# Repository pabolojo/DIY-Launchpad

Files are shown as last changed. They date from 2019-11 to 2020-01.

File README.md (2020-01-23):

# DIY-Launchpad

## This project is a DIY Launchpad powered by an Arduino, it is compatible with every Music Production program or app which can recognize USB MIDI devices, like Ableton Live.

## Instructions:

1. First you will need to gather all the parts and tools shown below, which are required for this project:

### Parts
|Units| Name|Cost (€)| Image|
|:--:|:---:|:---:|:---:|
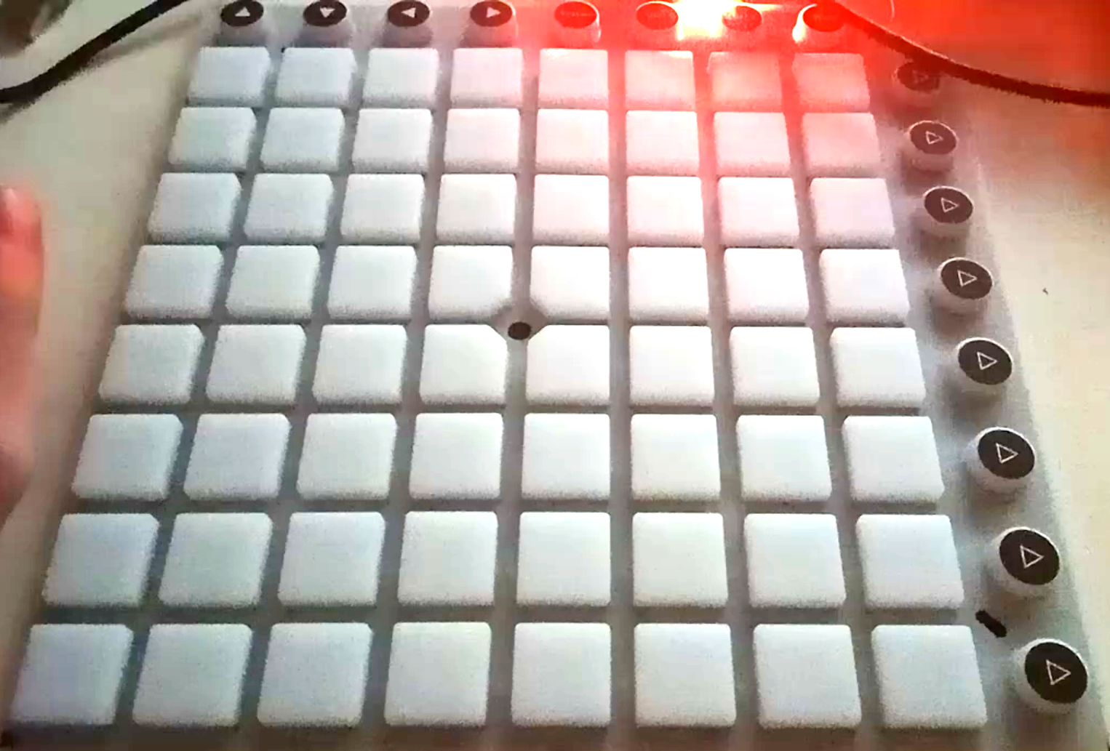
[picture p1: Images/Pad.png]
|1|Rubber Pad|20||
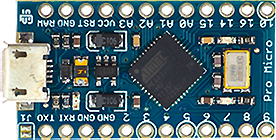
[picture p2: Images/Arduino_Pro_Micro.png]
|1|Arduino Pro Micro|2.5||
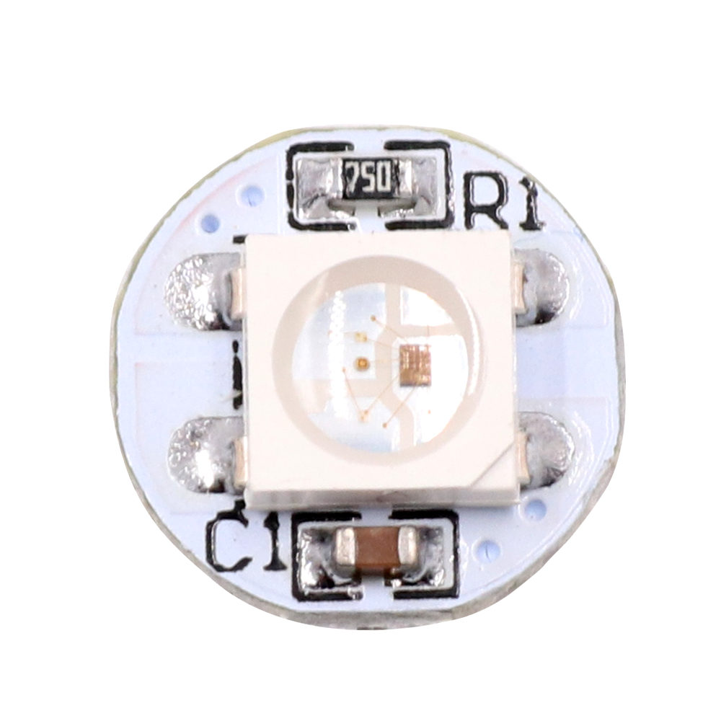
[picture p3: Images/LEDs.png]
|80|WS2812B RGB LEDs|8||
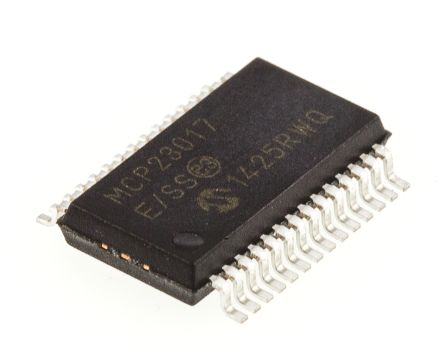
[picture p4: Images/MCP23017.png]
|5|MCP23017 - E/SS|4||
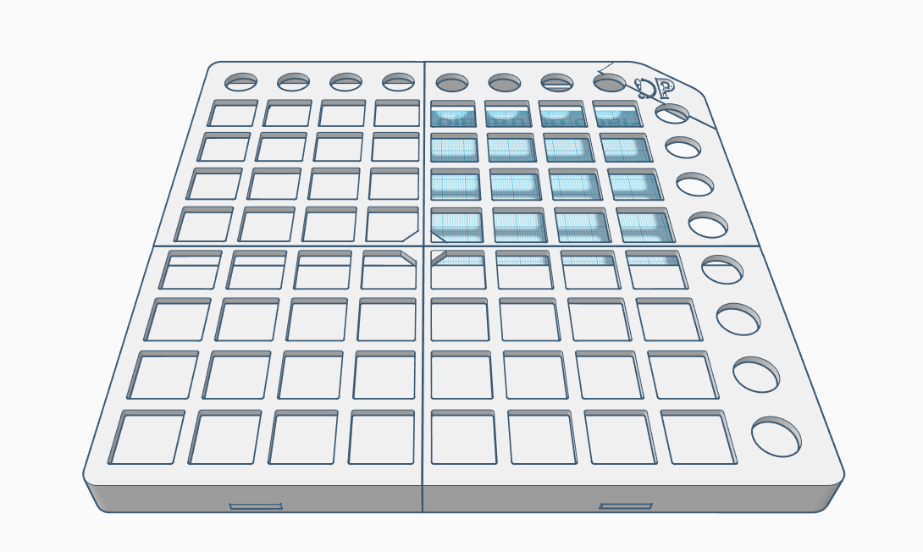
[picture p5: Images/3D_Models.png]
|1|3D Printed pieces Set|15||
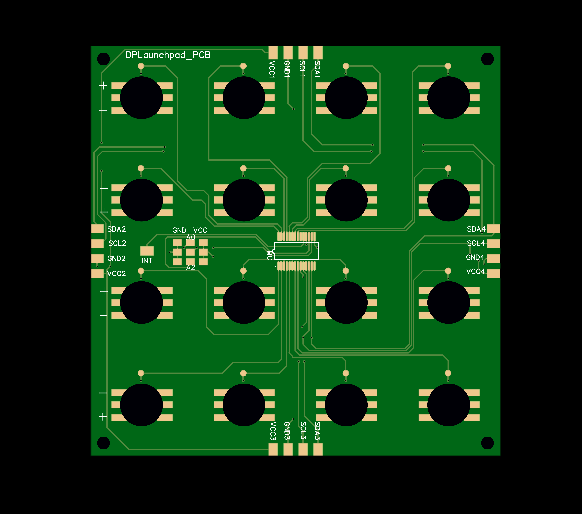
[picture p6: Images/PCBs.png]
|1|PCB Launchpad Set|10||

### Tools / Materials
|Name|Image|
|:---:|:---:|
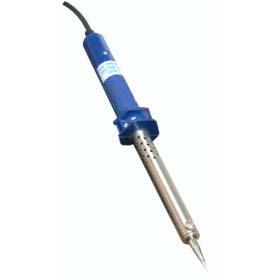
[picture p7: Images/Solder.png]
|Tin Solder||
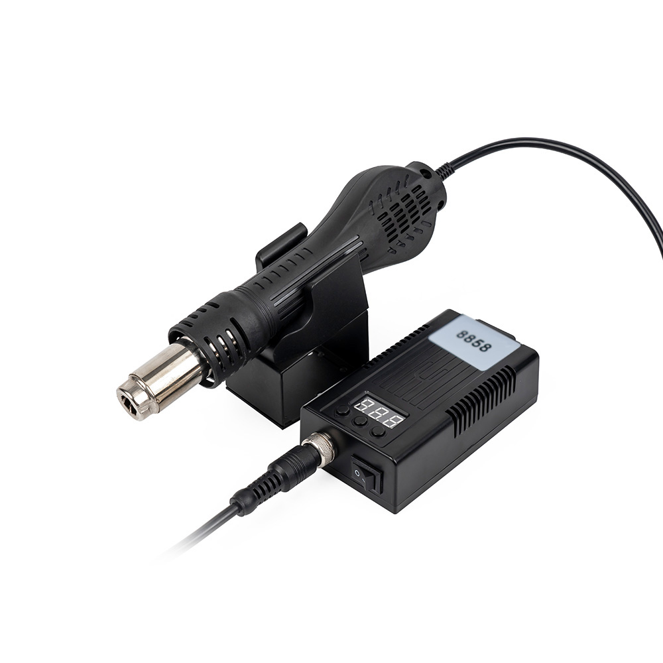
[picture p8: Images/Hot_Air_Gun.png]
|Hot Air Gun (Recommended)||
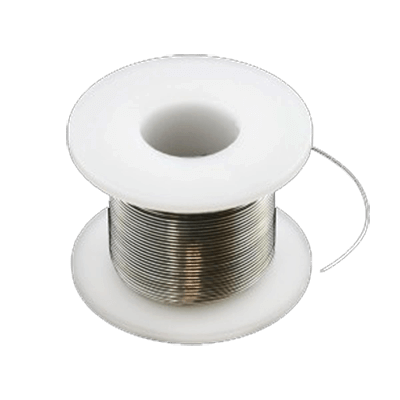
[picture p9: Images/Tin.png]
|Tin||
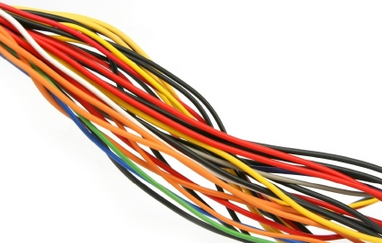
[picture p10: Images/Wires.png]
|Wires||

2. Then you will need to solder the MCP23017-E/SO integrated circuits to the PCBs using the Hot Air gun, as well as the PCBs one another connecting their pads, and the WS2812B RGB LEDs with the aid of the Tin Solder and metal wire. Assign an different address to each one of the PCBs by shortcuting A0, A1 and A2 either with GND or VCC. Then make the following connections between the Arduino Pro Micro and the PCBs:

|Arduino Pin|PCB Pad|
|:---:|:---:|
|2|SDA|
|3|SCL|
|VCC|VCC|
|GND|GND|

You may also make sure to connect the first WS2812B RGB LED of your array to the Arduino, connecting:

|Arduino Pin|LEDs Pad|
|:---:|:---:|
|VCC|VCC|
|GND|GND|
|10|DATA|

As well as the interrupt pads of the PCBs (grouping them by pairs) as shown:

|Arduino Pin|Interrupt (INT)|
|:---:|:---:|
|0|1 and 2|
|1|3 and 4|
|7|5|

The final result should be something like this:

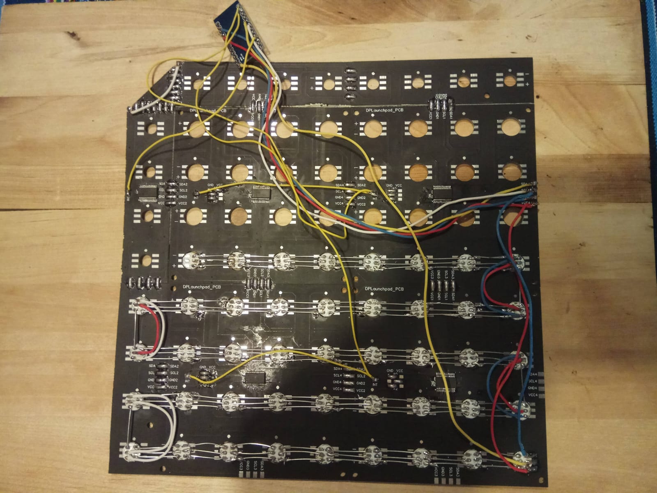
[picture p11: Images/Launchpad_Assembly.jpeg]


3. Flash the firmware to the Arduino Pro Micro, 3D print the housing, assembly everything and enjoy. :)



## This is still an ongoing project, and many things have to be fixed/improved yet, feel free to comment the project or make any suggestion you think it would make it better!

If you want to know what I am currently working on, visit http://psoetardgarcia.ga/

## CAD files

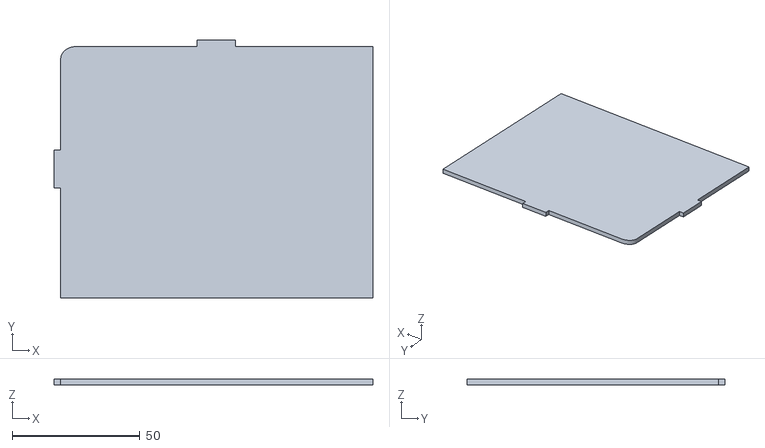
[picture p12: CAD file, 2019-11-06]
3D_Models/Launchpad_BR_C.stl
125.0 x 101.0 x 2.40

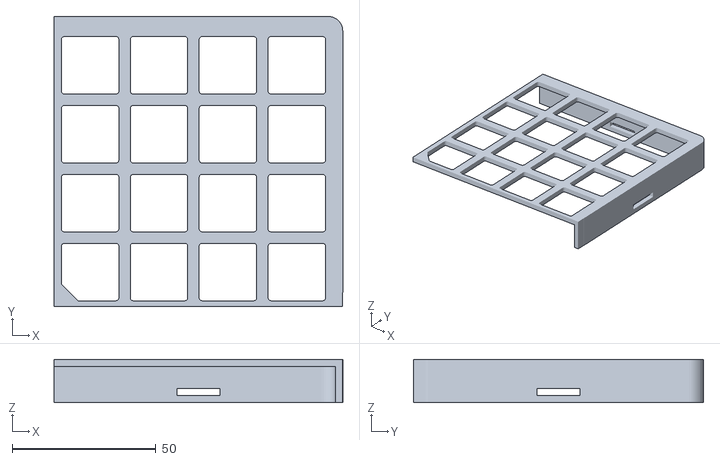
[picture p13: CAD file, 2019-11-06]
3D_Models/Launchpad_BL.stl
100.5 x 101.0 x 15.0

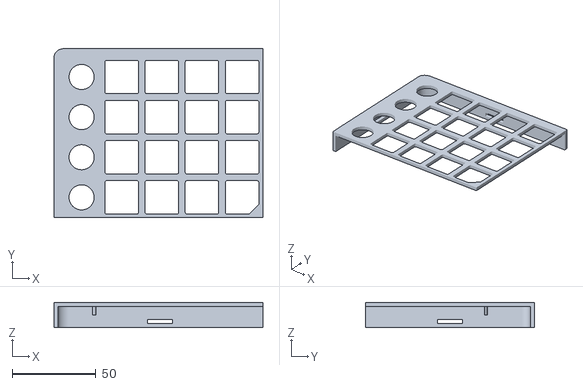
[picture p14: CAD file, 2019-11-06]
3D_Models/Launchpad_BR.stl
125.0 x 101.0 x 15.0

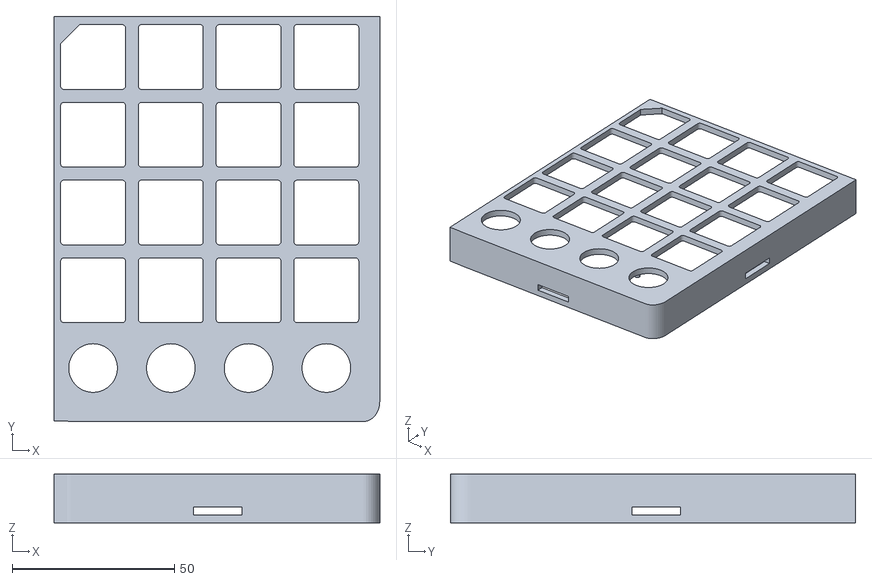
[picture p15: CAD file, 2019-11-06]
3D_Models/Launchpad_TL.stl
100.5 x 125.0 x 15.0

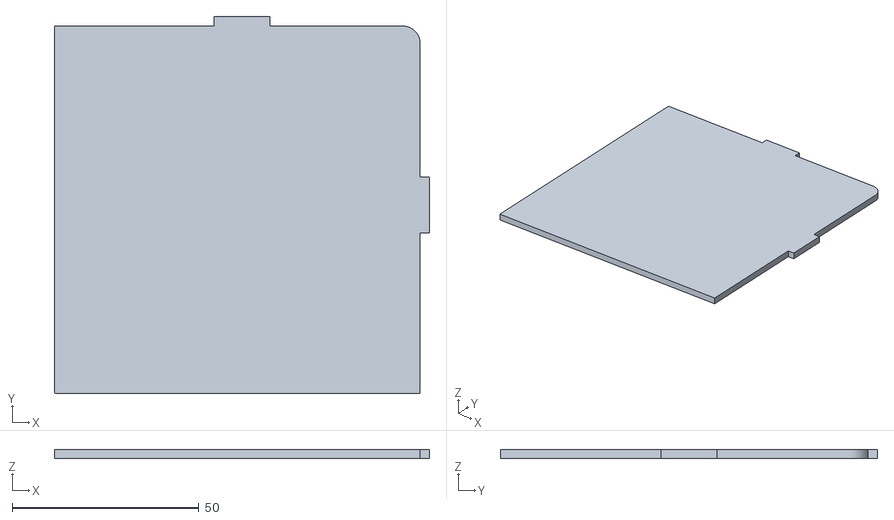
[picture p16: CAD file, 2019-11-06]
3D_Models/Launchpad_BL_C.stl
100.5 x 101.0 x 2.40

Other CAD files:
3D_Models/Launchpad_TL_C.stl

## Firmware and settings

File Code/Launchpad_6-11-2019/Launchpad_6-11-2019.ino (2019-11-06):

#include <Wire.h>
#include "MIDIUSB.h"
#include "FastLED.h"

#define NUM_LEDS 44
#define DATA_PIN 10
CRGB leds[NUM_LEDS];

// MCP23017 registers (everything except direction defaults to 0)

#define IODIRA   0x00   // IO direction  (0 = output, 1 = input (Default))
#define IODIRB   0x01
#define IOPOLA   0x02   // IO polarity   (0 = normal, 1 = inverse)
#define IOPOLB   0x03
#define GPINTENA 0x04   // Interrupt on change (0 = disable, 1 = enable)
#define GPINTENB 0x05
#define DEFVALA  0x06   // Default comparison for interrupt on change (interrupts on opposite)
#define DEFVALB  0x07
#define INTCONA  0x08   // Interrupt control (0 = interrupt on change from previous, 1 = interrupt on change from DEFVAL)
#define INTCONB  0x09
#define IOCON    0x0A   // IO Configuration: bank/mirror/seqop/disslw/haen/odr/intpol/notimp
//#define IOCON 0x0B  // same as 0x0A
#define GPPUA    0x0C   // Pull-up resistor (0 = disabled, 1 = enabled)
#define GPPUB    0x0D
#define INFTFA   0x0E   // Interrupt flag (read only) : (0 = no interrupt, 1 = pin caused interrupt)
#define INFTFB   0x0F
#define INTCAPA  0x10   // Interrupt capture (read only) : value of GPIO at time of last interrupt
#define INTCAPB  0x11
#define GPIOA    0x12   // add1 value. Write to change, read to obtain value
#define GPIOB    0x13
#define OLLATA   0x14   // Output latch. Write to latch output.
#define OLLATB   0x15


#define add1 0x20  // MCP23017 is on I2C add1 0x20
#define add2 0x21
#define add3 0x22
#define add4 0x24
#define add5 0x27

bool State[80] = {0};

const unsigned long colors[] = {
  0x000000,0xfafafa,0xfafafa,0xfafafa,0xf8bbd0,0xef5350,0xe57373,0xef9a9a,
  0xfff3e0,0xffa726,0xffb960,0xffcc80,0xffe0b2,0xffee58,0xfff59d,0xfff9c4,
  0xdcedc8,0x8bc34a,0xaed581,0xbfdf9f,0x5ee2b0,0x00ce3c,0x00ba43,0x119c3f,
  0x57ecc1,0x00e864,0x00e05c,0x00d545,0x7afddd,0x00e4c5,0x00e0b2,0x01eec6,
  0x49efef,0x00e7d8,0x00e5d1,0x01efde,0x6addff,0x00dafe,0x01d6ff,0x08acdc,
  0x73cefe,0x0d9bf7,0x148de4,0x2a77c9,0x8693ff,0x2196f3,0x4668f6,0x4153dc,
  0xb095ff,0x8453fd,0x634acd,0x5749c5,0xffb7ff,0xe863fb,0xd655ed,0xd14fe9,
  0xfc99e3,0xe736c2,0xe52fbe,0xe334b6,0xed353e,0xffa726,0xf4df0b,0x8bc34a,
  0x5cd100,0x00d29e,0x2388ff,0x3669fd,0x00b4d0,0x475cdc,0xfafafa,0xfafafa,
  0xf72737,0xd2ea7b,0xc8df10,0x7fe422,0x00c931,0x00d7a6,0x00d8fc,0x0b9bfc,
  0x585cf5,0xac59f0,0xd980dc,0xb8814a,0xff9800,0xabdf22,0x9ee154,0x66bb6a,
  0x3bda47,0x6fdeb9,0x27dbda,0x9cc8fd,0x79b8f7,0xafafef,0xd580eb,0xf74fca,
  0xea8a1f,0xdbdb08,0x9cd60d,0xf3d335,0xc8af41,0x00ca69,0x24d2b0,0x757ebe,
  0x5388db,0xe5c5a6,0xe93b3b,0xf9a2a1,0xed9c65,0xe1ca72,0xb8da78,0x98d52c,
  0x626cbd,0xcac8a0,0x90d4c2,0xceddfe,0xbeccf7,0xfafafa,0xfafafa,0xfafafa,
  0xfe1624,0xcd2724,0x9ccc65,0x009c1b,0xffff00,0xbeb212,0xf5d01d,0xe37829
  };

void noteOn(byte channel, byte pitch, byte velocity) {
  midiEventPacket_t noteOn = {0x09, 0x90 | channel, pitch, velocity};
  MidiUSB.sendMIDI(noteOn);
  MidiUSB.flush();
}

void noteOff(byte channel, byte pitch, byte velocity) {
  midiEventPacket_t noteOff = {0x08, 0x80 | channel, pitch, velocity};
  MidiUSB.sendMIDI(noteOff);
  MidiUSB.flush();
}
volatile bool keyPressed1 = false, keyPressed2 = false, keyPressed3 = false;

// set register "reg" on expander to "data"
// for example, IO direction
void expanderWriteBoth (const byte addr, const byte reg, const byte data ) 
{
  Wire.beginTransmission (addr);
  Wire.write (reg);
  Wire.write (data);  // add1 A
  Wire.write (data);  // add1 B
  Wire.endTransmission ();
} // end of expanderWrite

// read a byte from the expander
unsigned int expanderRead (const byte addr, const byte reg) 
{
  Wire.beginTransmission (addr);
  Wire.write (reg);
  Wire.endTransmission ();
  Wire.requestFrom (addr, 1);
  return Wire.read();
} // end of expanderRead

void keypress0()
{
  keyPressed1 = true;
}

void keypress1()
{
  keyPressed2 = true;
}

void keypress2()
{
  keyPressed3 = true;
}

void matrix_ini(const byte addr){
   // expander configuration register
  expanderWriteBoth (addr, IOCON, 0b01100000); // mirror interrupts, disable sequential mode
 
  // enable pull-up on switches
  expanderWriteBoth (addr, GPPUA, 0xFF);   // pull-up resistor for switch - both add1s

  // invert polarity
  expanderWriteBoth (addr, IOPOLA, 0xFF);  // invert polarity of signal - both add1s
  
  // enable all interrupts
  expanderWriteBoth (addr, GPINTENA, 0xFF); // enable interrupts - both add1s
  
  // read from interrupt capture add1s to clear them
  expanderRead (addr, INTCAPA);
  expanderRead (addr, INTCAPB);
}

void setup ()
{
  delay(1000);
  Wire.begin ();  

  //Serial.begin(115200);
  
  matrix_ini(add1);
  matrix_ini(add2);
  matrix_ini(add3);
  matrix_ini(add4);
  matrix_ini(add5);

  FastLED.addLeds<WS2812B, DATA_PIN, GRB>(leds, NUM_LEDS);
  FastLED.setBrightness(30);

  attachInterrupt(2, keypress0, FALLING);
  attachInterrupt(3, keypress1, FALLING);
  attachInterrupt(digitalPinToInterrupt(7), keypress2, FALLING);
}

unsigned int keyValue1 = 0, keyValue2 = 0, keyValue3 = 0, keyValue4 = 0, keyValue5 = 0;

void change_on(byte button, byte change){
  //Serial.println(String(button) + " , " + String(change));
  if(change==1){
    noteOn(0,button,127);
  }
  else{
    noteOff(0,button,0);
  }
}

byte get_index(const byte addr){
  switch(addr){
    case add1:
      return 0;
    case add2:
      return 1;
    case add3:
      return 2;
    case add4:
      return 3;
    case add5:
      return 4;
  }
}

byte get_button_num(const byte button, const byte pad){
  byte good_arr[16]={11,15,10,14,13,9,12,8,4,0,5,1,2,6,3,7};
  if(pad==0 || pad==1){
    return 16*(good_arr[button]/4)+good_arr[button]%4+pad*4;
  }
  else{
    return 64 + 16*(good_arr[button]/4)+good_arr[button]%4+(pad-2)*4;
  }
}

// called from main loop when we know we had an interrupt
void handleKeypress (const byte addr, unsigned int *keyValue)
{
  
  delay (10);  // de-bounce before we re-enable interrupts
  
  // Read add1 values, as required. Note that this re-arms the interrupts.
  if (expanderRead (addr, INFTFA))
    {
    *keyValue &= 0x00FF;
    *keyValue |= expanderRead (addr, INTCAPA) << 8;    // read value at time of interrupt
    }
  if (expanderRead (addr, INFTFB))
    {
    *keyValue &= 0xFF00;
    *keyValue |= expanderRead (addr, INTCAPB);        // add1 B is in low-order byte
    }
}

void led(int i, int velo){
  if(i>111 && i<121){
    leds[i-112]=colors[velo];
  }
  else if(i>95 && i<105){
    leds[113-i]=colors[velo];
  }
  else if(i>79 && i<89){
    leds[i-62]=colors[velo];
  }
  else if(i>63 && i<73){
    leds[99-i]=colors[velo];
  }
  else if(i>47 && i<57){
    leds[i-12]=colors[velo];
  }
}

void set_leds(midiEventPacket_t rx){
  byte comm = rx.header;
  byte sig = rx.byte1;
  byte note = rx.byte2;
  byte velo = rx.byte3;
  led(note,velo);
}

void loop ()
{
  if (keyPressed1){
    keyPressed1 = false;
    handleKeypress(add1, &keyValue1);
    handleKeypress(add2, &keyValue2);
    //Serial.println("Interrupt 1: "+String(keyValue1)+" , "+String(keyValue2));
    for (byte button = 0; button < 16; button++){
      if (keyValue1 & (1 << button)){
        if(State[button]!=1){
          State[button]=1;
          change_on(get_button_num(button,0),1);
        }
      }
      else{
        if(State[button]!=0){
          State[button]=0;
          change_on(get_button_num(button,0),0);
        }
      }
      
      if (keyValue2 & (1 << button)){
        if(State[button+16]!=1){
          State[button+16]=1;
          change_on(get_button_num(button,1),1);
        }
      }
      else{
        if(State[button+16]!=0){
          State[button+16]=0;
          change_on(get_button_num(button,1),0);
        }
      }
    }
  }
  else if(keyPressed2){
    keyPressed2 = false;
    handleKeypress(add3, &keyValue3);
    handleKeypress(add4, &keyValue4);
    //Serial.println("Interrupt 2: "+String(keyValue3)+" , "+String(keyValue4));
    for (byte button = 0; button < 16; button++){
      if (keyValue3 & (1 << button)){
        if(State[button+32]!=1){
          State[button+32]=1;
          change_on(get_button_num(button,2),1);
        }
      }
      else{
        if(State[button+32]!=0){
          State[button+32]=0;
          change_on(get_button_num(button,2),0);
        }
      }
      
      if (keyValue4 & (1 << button)){
        if(State[button+48]!=1){
          State[button+48]=1;
          change_on(get_button_num(button,3),1);
        }
      }
      else{
        if(State[button+48]!=0){
          State[button+48]=0;
          change_on(get_button_num(button,3),0);
        }
      }
    }
  }
  
  else if(keyPressed3){
    keyPressed3 = false;
    handleKeypress(add5, &keyValue5);
    for (byte button = 0; button < 16; button++){
      if (keyValue5 & (1 << button)){
        if(State[button+64]!=1){
          State[button+64]=1;
          leds[button]=colors[(button+1)*7];
          //change_on(get_button_num(button,2),1);
        }
      }
      else{
        if(State[button+64]!=0){
          State[button+64]=0;
          leds[button]=colors[0];
          //change_on(get_button_num(button,2),0);
        }
      }
    }
  }
  midiEventPacket_t rx;
  do {
    rx = MidiUSB.read();
    if (rx.header != 0) {
      set_leds(rx);
    }
  } while (rx.header != 0);
  
  FastLED.show();
}
/*
// Author: Nick Gammon
// Date: 19 February 2011

// Demonstration of an interrupt service routine connected to the MCP23017

#include <Wire.h>
#include "MIDIUSB.h"
#include "FastLED.h"

// MCP23017 registers (everything except direction defaults to 0)

#define IODIRA   0x00   // IO direction  (0 = output, 1 = input (Default))
#define IODIRB   0x01
#define IOPOLA   0x02   // IO polarity   (0 = normal, 1 = inverse)
#define IOPOLB   0x03
#define GPINTENA 0x04   // Interrupt on change (0 = disable, 1 = enable)
#define GPINTENB 0x05
#define DEFVALA  0x06   // Default comparison for interrupt on change (interrupts on opposite)
#define DEFVALB  0x07
#define INTCONA  0x08   // Interrupt control (0 = interrupt on change from previous, 1 = interrupt on change from DEFVAL)
#define INTCONB  0x09
#define IOCON    0x0A   // IO Configuration: bank/mirror/seqop/disslw/haen/odr/intpol/notimp
//#define IOCON 0x0B  // same as 0x0A
#define GPPUA    0x0C   // Pull-up resistor (0 = disabled, 1 = enabled)
#define GPPUB    0x0D
#define INFTFA   0x0E   // Interrupt flag (read only) : (0 = no interrupt, 1 = pin caused interrupt)
#define INFTFB   0x0F
#define INTCAPA  0x10   // Interrupt capture (read only) : value of GPIO at time of last interrupt
#define INTCAPB  0x11
#define GPIOA    0x12   // Port value. Write to change, read to obtain value
#define GPIOB    0x13
#define OLLATA   0x14   // Output latch. Write to latch output.
#define OLLATB   0x15
#define NUM_LEDS 8
#define DATA_PIN 10
CRGB leds[NUM_LEDS];

#define port 0x24  // MCP23017 is on I2C port 0x20

volatile bool keyPressed;
bool State[80] = {0};

void noteOn(byte channel, byte pitch, byte velocity) {
  midiEventPacket_t noteOn = {0x09, 0x90 | channel, pitch, velocity};
  MidiUSB.sendMIDI(noteOn);
  MidiUSB.flush();
}

void noteOff(byte channel, byte pitch, byte velocity) {
  midiEventPacket_t noteOff = {0x08, 0x80 | channel, pitch, velocity};
  MidiUSB.sendMIDI(noteOff);
  MidiUSB.flush();
}

// set register "reg" on expander to "data"
// for example, IO direction
void expanderWriteBoth (const byte reg, const byte data ) 
{
  Wire.beginTransmission (port);
  Wire.write (reg);
  Wire.write (data);  // port A
  Wire.write (data);  // port B
  Wire.endTransmission ();
} // end of expanderWrite

// read a byte from the expander
unsigned int expanderRead (const byte reg) 
{
  Wire.beginTransmission (port);
  Wire.write (reg);
  Wire.endTransmission ();
  Wire.requestFrom (port, 1);
  return Wire.read();
} // end of expanderRead

// interrupt service routine, called when pin D2 goes from 1 to 0
void keypress ()
{
  keyPressed = true;   // set flag so main loop knows
}  // end of keypress

void setup ()
{
  delay(800);
  Wire.begin ();  
  Serial.begin (115200); 

  // expander configuration register
  expanderWriteBoth (IOCON, 0b01100000); // mirror interrupts, disable sequential mode
 
  // enable pull-up on switches
  expanderWriteBoth (GPPUA, 0xFF);   // pull-up resistor for switch - both ports

  // invert polarity
  expanderWriteBoth (IOPOLA, 0xFF);  // invert polarity of signal - both ports
  
  // enable all interrupts
  expanderWriteBoth (GPINTENA, 0xFF); // enable interrupts - both ports
  
  // no interrupt yet
  keyPressed = false;

  // read from interrupt capture ports to clear them
  expanderRead (INTCAPA);
  expanderRead (INTCAPB);
  
  FastLED.addLeds<WS2812B, DATA_PIN, GRB>(leds, NUM_LEDS);
  FastLED.setBrightness(30);
  // pin 19 of MCP23017 is plugged into D2 of the Arduino which is interrupt 0
  attachInterrupt(3, keypress, FALLING);
  
}  // end of setup

// time we turned LED on
unsigned int keyValue = 0;

// called from main loop when we know we had an interrupt
void handleKeypress ()
{
  
  delay (10);  // de-bounce before we re-enable interrupts
  
  keyPressed = false;  // ready for next time through the interrupt service routine
  
  // Read port values, as required. Note that this re-arms the interrupts.
  if (expanderRead (INFTFA))
    {
    keyValue &= 0x00FF;
    keyValue |= expanderRead (INTCAPA) << 8;    // read value at time of interrupt
    }
  if (expanderRead (INFTFB))
    {
    keyValue &= 0xFF00;
    keyValue |= expanderRead (INTCAPB);        // port B is in low-order byte
    }
  
}

void change_on(byte button, byte change){
  //Serial.println(String(button) + " , " + String(change));
  if(change==1){
    noteOn(0,button,127);
    leds[button-83]=0x00d7a6;
  }
  else{
    noteOff(0,button,0);
    leds[button-83]=0x000000;
  }
  FastLED.show();
}

byte get_button_num(const byte button, const byte pad){
  byte good_arr[16]={11,15,10,14,13,9,12,8,4,0,5,1,2,6,3,7};
  if(pad==0 || pad==1){
    return 16*(good_arr[button]/4)+good_arr[button]%4+pad*4;
  }
  else{
    return 64 + 16*(good_arr[button]/4)+good_arr[button]%4+(pad-2)*4;
  }
}

void loop ()
{
  // was there an interrupt?
  if (keyPressed){
    handleKeypress ();
    for (byte button = 0; button < 16; button++){
      if (keyValue & (1 << button)){
        if(State[button+48]!=1){
          State[button+48]=1;
          change_on(get_button_num(button,3),1);
        }
      }
      else{
        if(State[button+48]!=0){
          State[button+48]=0;
          change_on(get_button_num(button,3),0);
        }
      }
    }
  }
  midiEventPacket_t rx;
  do {
    rx = MidiUSB.read();
    if (rx.header != 0) {
      //set_leds(rx);
    }
  } while (rx.header != 0);
}  // end of loop
 */
/*
#include <USBComposite.h>

const uint8_t notes[] = {60, 62, 64, 65, 67, 69, 71, 72, 61, 63, 66, 68, 70};
const int numNotes = sizeof(notes)/sizeof(*notes);

class myMidi : public USBMIDI {
 virtual void handleNoteOff(unsigned int channel, unsigned int note, unsigned int velocity) {
 }
 virtual void handleNoteOn(unsigned int channel, unsigned int note, unsigned int velocity) {
  }
  
};

myMidi midi;
USBCompositeSerial CompositeSerial;

void setup() {
    USBComposite.setProductId(0x0030);
    midi.registerComponent();
    CompositeSerial.registerComponent();
    USBComposite.begin();
    Serial.begin(9600);
}

void loop() {
  midi.poll();
  for (int i=0;i<numNotes;i++) {
    midi.sendNoteOn(0, notes[i], 127);
    delay(500);
    midi.sendNoteOff(0, notes[i], 127);
  }
}*/
